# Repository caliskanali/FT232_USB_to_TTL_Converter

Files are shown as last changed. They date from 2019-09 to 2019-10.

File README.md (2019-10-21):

# FT232_USB_to_TTL_Converter
I designed the TTL converter myself for use in electronic circuits and projects. 
It is a project that I realized with the spnsorship of PCBway.
Again, I will share the production files publicly on the PCBway web site. If you want to order, you can access from the link below.
https://www.pcbway.com/project/shareproject/FT232_USB_to_TTL_Converter.html
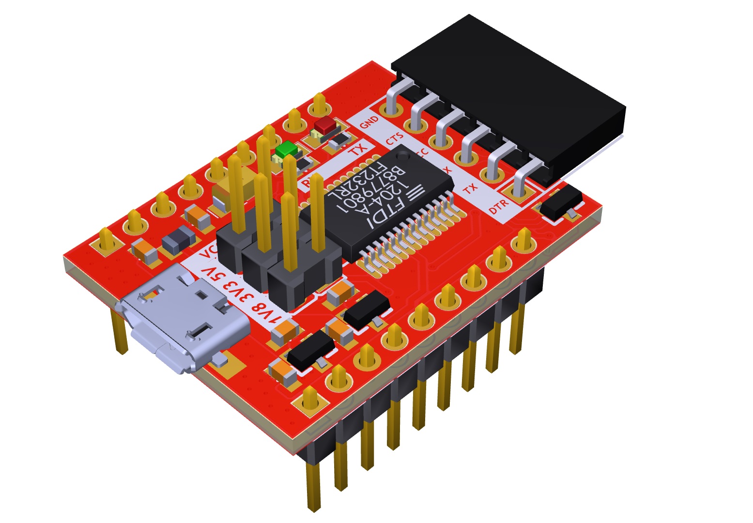
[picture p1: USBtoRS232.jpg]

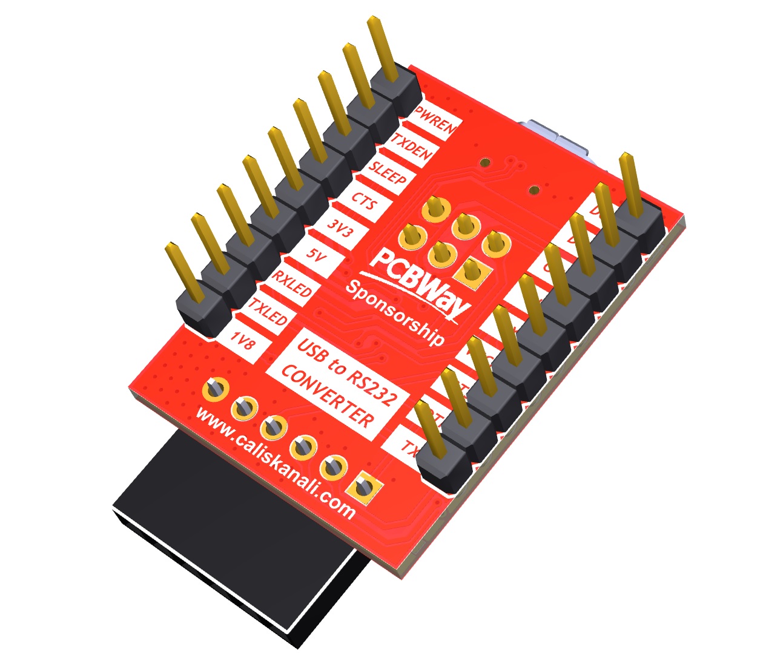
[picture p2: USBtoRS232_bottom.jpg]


To do this, I used the FT232RL integrated by the FTDI company and made some changes from the reference scheme.
# SCHEMATIC BLOG DIAGRAM
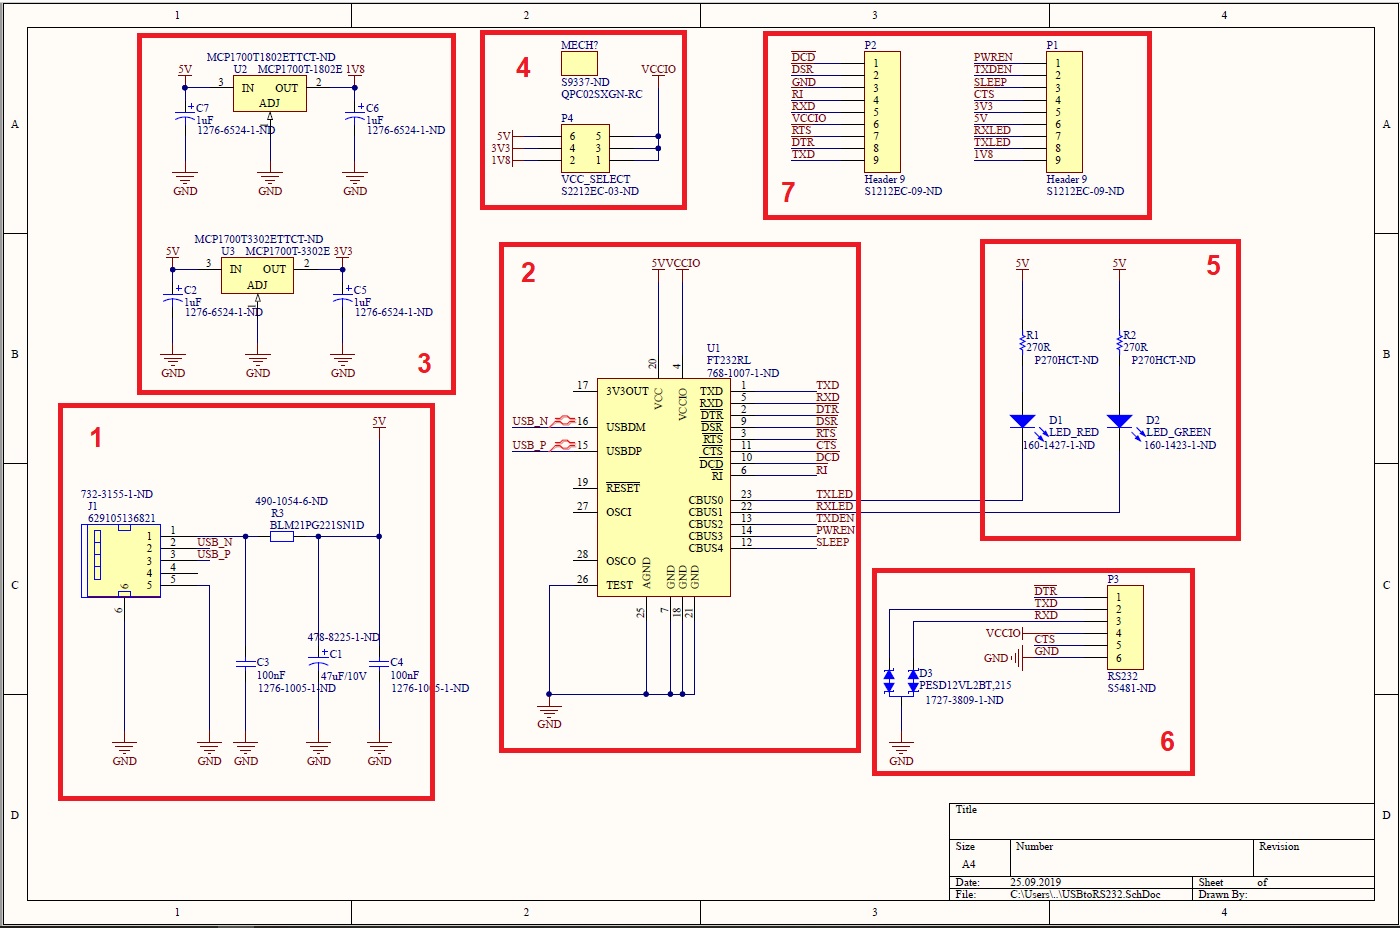
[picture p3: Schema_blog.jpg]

The first is to adjust the IO voltage. By adding 2 regulators to the diagram (3), we have switchable IO voltage of 1.8V - 3.3V and 5V. (4)
RX - TX data LEDs added. (5) On the output port, I added a TVS diode for external ESD protection to the Tx and Rx pins (6).

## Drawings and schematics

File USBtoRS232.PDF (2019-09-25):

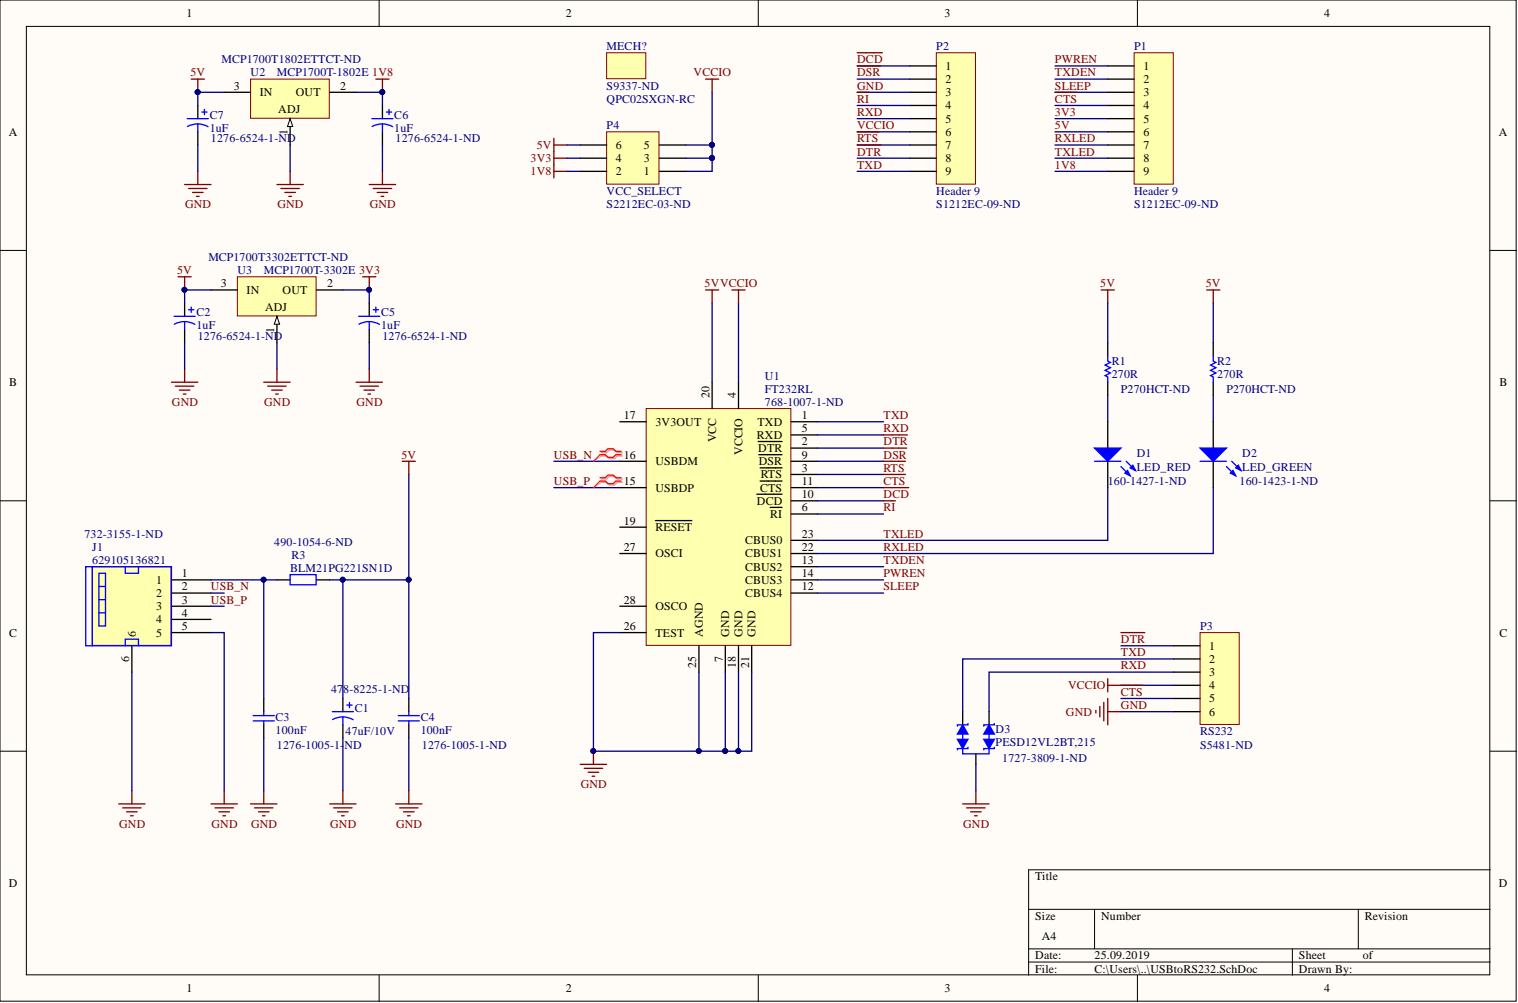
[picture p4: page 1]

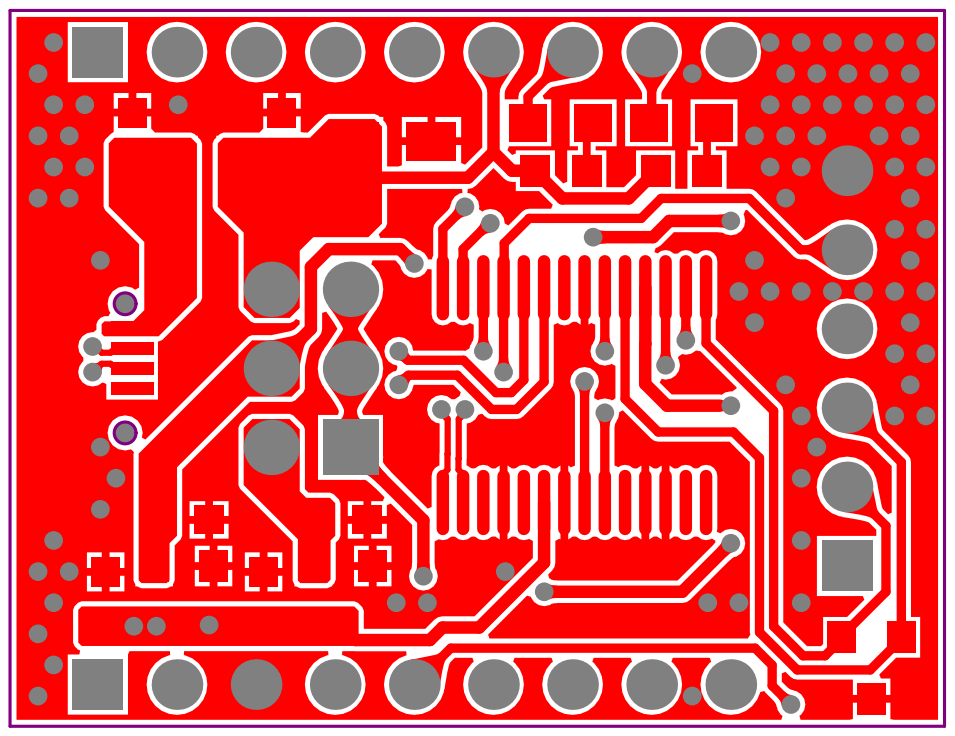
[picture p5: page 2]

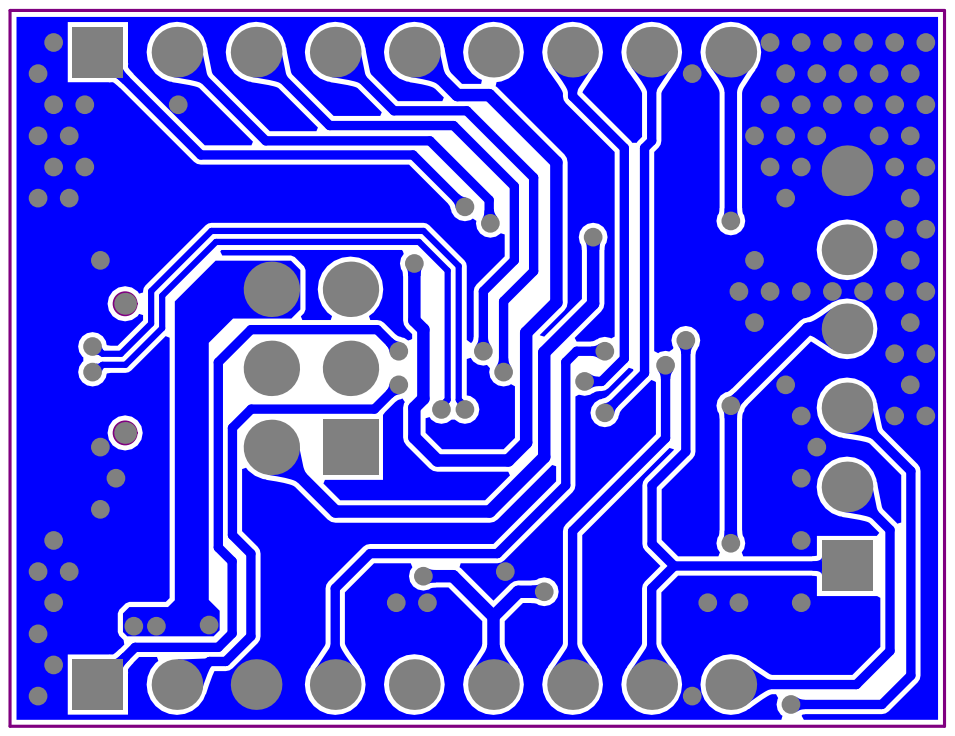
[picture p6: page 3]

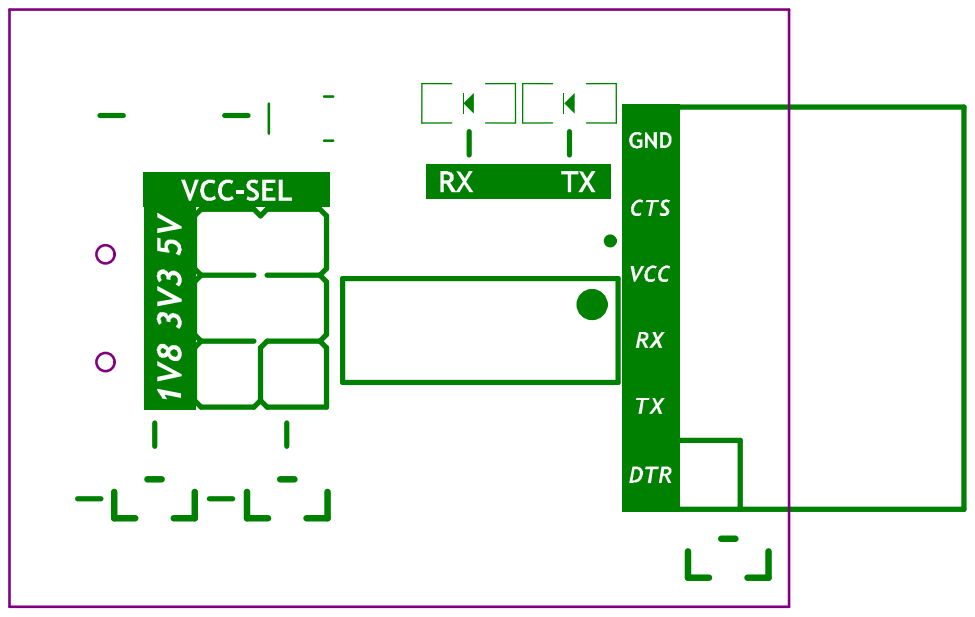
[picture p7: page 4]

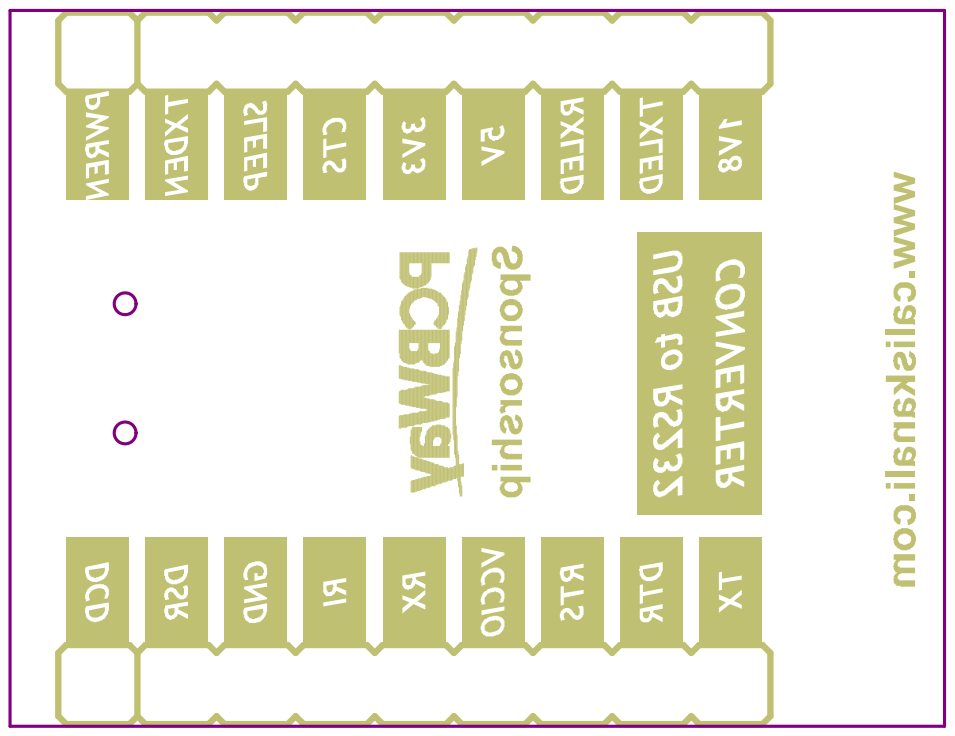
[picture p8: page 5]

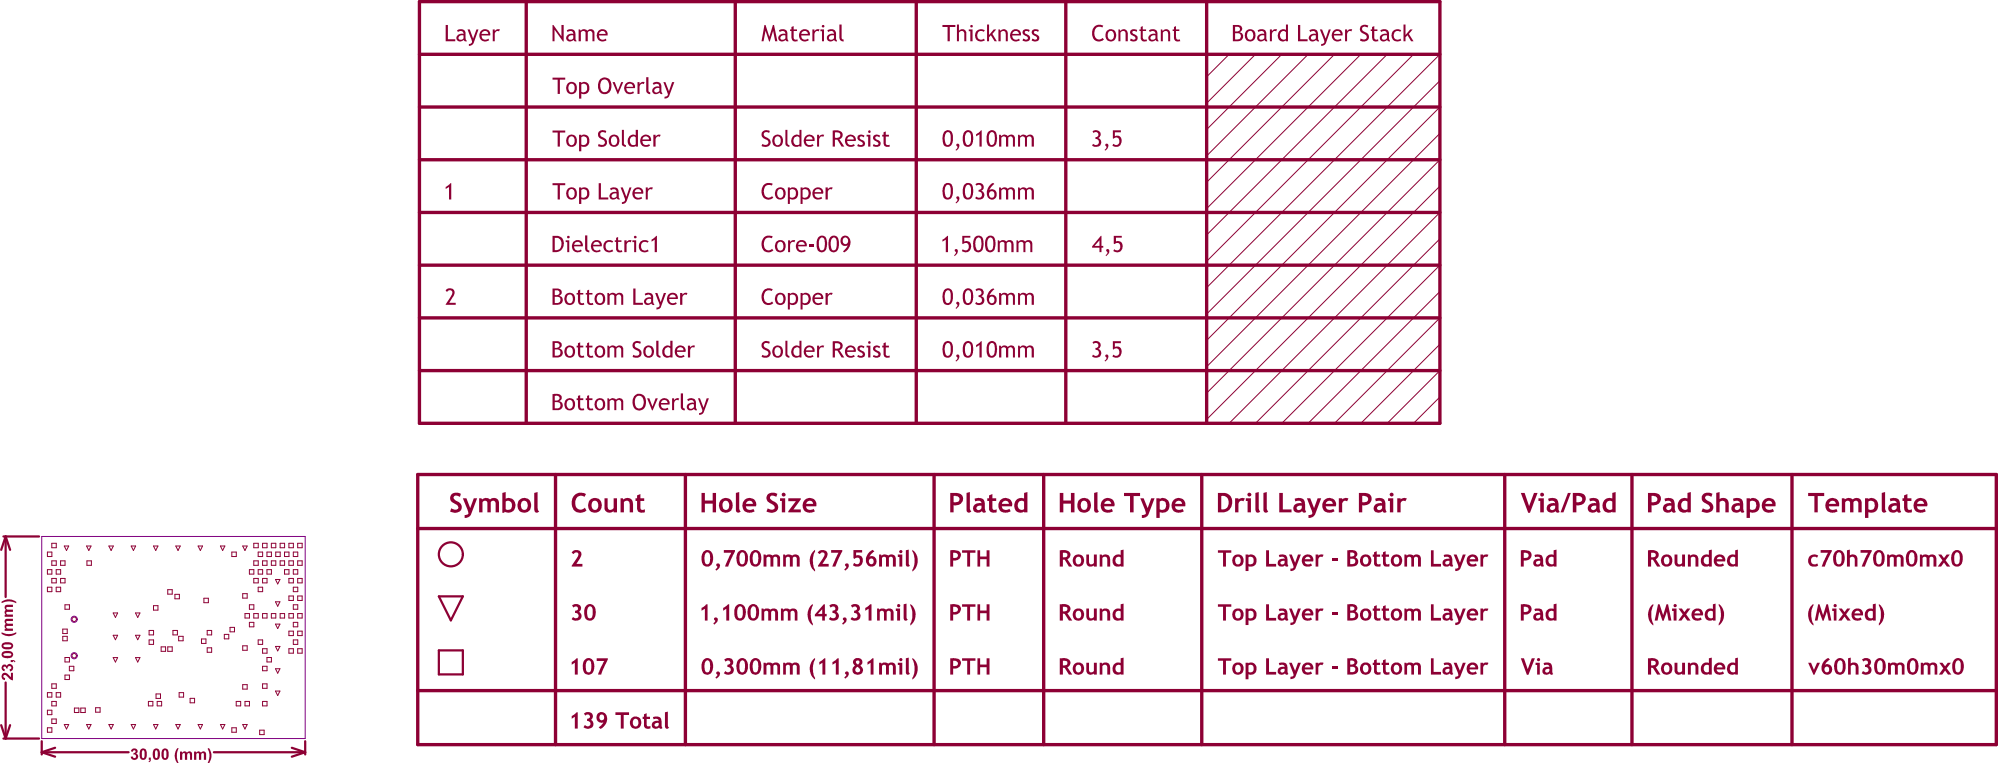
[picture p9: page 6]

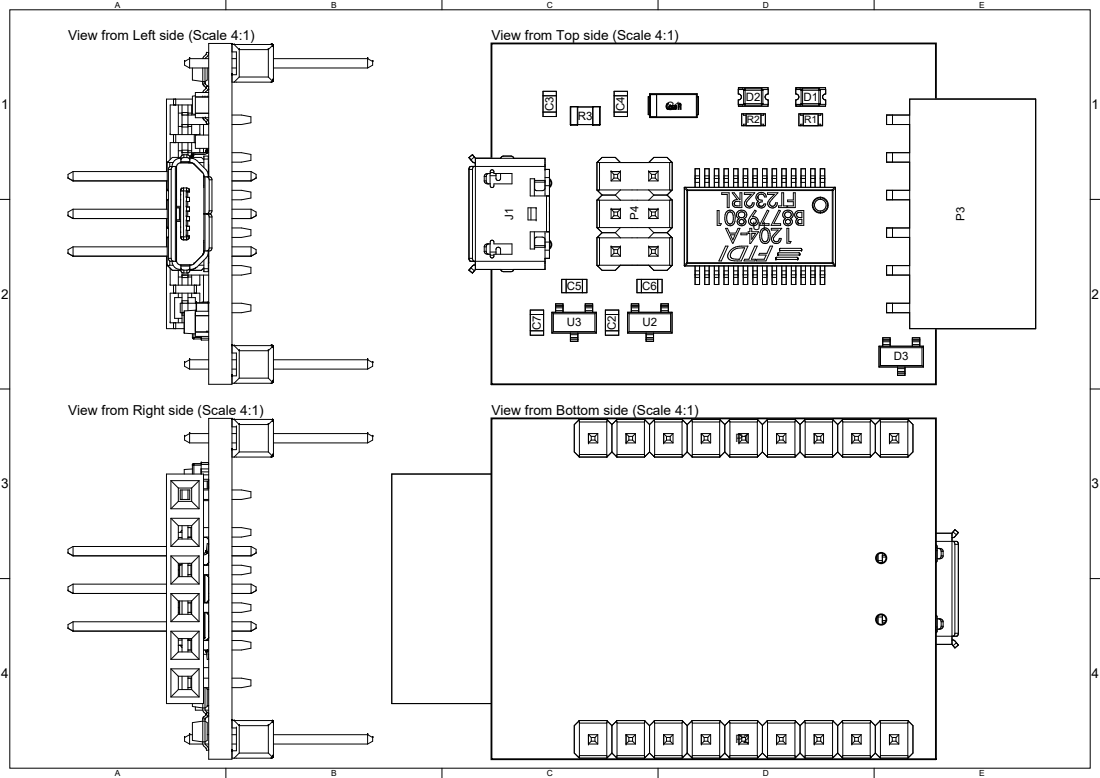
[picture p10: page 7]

View from Left side (Scale 4:1)

View from Top side (Scale 4:1)

View from Right side (Scale 4:1)

View from Bottom side (Scale 4:1)

Comment | Description | Designator | Case/Package | Manufacturer 1 | Manufacturer Part Number 1Supplier 1 | | Supplier Part Number 1 | Quantity
47uF/10V | CAP TANT 47UF 20% C1 | | | AVX | F931A476MAA | Digi-Key | 478-8225-1-ND | 1
1uF | Ceramic Capacitor (SuC2, C 5, C 6, C 7 | | 0603 | Samsung | CL10B105MO8NNWC | Digi-Key | 1276-6524-1-ND | 4
100nF | Ceramic Capacitor (SuC3, C4 | | 0603 | Samsung | CL10B104KO8NNNC | Digi-Key | 1276-1005-1-ND | 2
LED_RED | LED RED CLEAR SMD | D1 | 0805 | Lite-On | LTST-C171KRKT | Digi-Key | 160-1427-1-ND | 1
LED_GREEN | LED GREEN CLEAR CHD2 | | 0805 | Lite-On | LTST-C171GKT | Digi-Key | 160-1423-1-ND | 1
PESD12VL2BT,215 | TVS DIODE 12V 37V SD3 | | | Nexperia | PESD12VL2BT,215 | Digi-Key | 1727-3809-1-ND | 1
629105136821 | CONN RCPT USB2.0 MIJ1 | | | Würth Elektronik | 629105136821 | Digi-Key | 732-3155-1-ND | 1
QPC02SXGN-RC | CONN JUMPER SHORTMEC H? | | 100 | Sullins | QPC02SXGN-RC | Digi-Key | S9337-ND | 1
Header 9 | CONN HEADER VERT | 9PP1, P 2 | | Sullins | PREC009SFAN-RC | Digi-Key | S1212EC-09-ND | 2
RS232 | CONN HDR 6POS 0.1 GP3 | | | Sullins | PPPC061LGBN-RC | Digi-Key | S5481-ND | 1
VCC_SELECT | CONN HEADER VERT | 6PP4 | | Sullins | PREC003DFAN-RC | Digi-Key | S2212EC-03-ND | 1
270R | Resistor | R1, R2 | 0603 | Panasonic | ERJ-3EKF2700V | Digi-Key | P270HCT-ND | 2
BLM21PG221SN1D | FERRITE BEAD 220 OHR3 | | 0805 | Murata | BLM21PG221SN1D | Digi-Key | 490-1054-6-ND | 1
FT232RL | FT232R USB UART | U1 | SSOP | FTDI | FT232RL-REEL | Digi-Key | 768-1007-1-ND | 1
MCP1700T-1802E | Three-Terminal AdjusU2 | | SOT-23 | Microchip | MCP1700T-1802E/TT | Digi-Key | MCP1700T1802ETTCT-ND | 1
MCP1700T-3302E | Three-Terminal AdjusU3 | | SOT-23 | Microchip | MCP1700T-3302E/TT | Digi-Key | MCP1700T3302ETTCT-ND | 1

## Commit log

2019-09-25 Add files via upload
    the component package on the printed circuit board were changed and redrawn.
    [USBtoRS232-Panel_3x3.PcbDoc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]
2019-10-21 Update README.md
    pcbway link updated
